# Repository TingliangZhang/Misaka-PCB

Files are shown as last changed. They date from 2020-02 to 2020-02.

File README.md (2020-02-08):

# Misaka-PCB

计划在设计完SCH电路图之后，改用KiCAD画，并全程录屏做延时视频。

## BOM智能配单

https://bom.szlcsc.com/bom.html

为了BOM配单方便，尽可能使用JLC-SMT库

[嘉立创](https://www.sz-jlc.com/)把 SMT支持的器件做成了要一个集成库

下载方法:   [嘉立创SMT](https://gitee.com/JLC_SMT) **/** [JLCSMT_LIB](https://gitee.com/JLC_SMT/JLCSMT_LIB)

导入Project Outputs for Miscellaneous Devices LC中的Miscellaneous Devices LC.IntLib

## USB 2.0 to USB Type-C

[**How to easily move from USB 2.0 to USB Type-C**](http://e2e.ti.com/blogs_/b/analogwire/archive/2015/09/02/how-to-easily-move-from-usb-2-0-to-usb-type-c)

[Oh Say Can You C? – Grappling with the USB type-C Connector](https://resources.orcad.com/orcad-blog/oh-say-can-you-c-grappling-with-the-usb-type-c-connector)

[Type-A接口改成Type-c接口的实验设计](http://www.elecfans.com/emb/jiekou/20190505929062.html)

## PCB Design Rules

SMD Pads Clearance -- 0.2 mil

TH Pads Clearance -- 0.15 mil

SMD Pads - Fill Clearance -- 0 mil   SMD Pads - Track -- 0 mil     XBEE模块的天线KEEPOUT FILL

## 元件选型说明

原Mega 2560中 LMV358IDGKR 立创商城需订货，改为LM358DR2G通用运放

原Mega 2560中 MH2029-300Y 磁珠 ，改为 BLM21PG300SN1D 0805 30 欧 @ 100MHz

MF-MSMF050 0.5A 15V 自恢复保险丝 立创商城需订货，改为 https://item.szlcsc.com/13192.html （相同封装）

俩RESET不要选元件

CG0603MLC-05E  ESD 抑制器/TVS 二极管，立创商城无货，改为[**0603ESDA-05N**](https://item.szlcsc.com/297742.html)

## PCB注意事项

和DTR 隔着100nF的Reset要连着和+5V隔着10kOhm的焊盘，以便SMT跳线能起作用。

X为水平左右翻转；Y为垂直上下翻转

## Cadence/OrCAD

Cadence Orcad Allegro Sigrity相关软件资源下载

https://www.mr-wu.cn/cadence-orcad-allegro-resource-downloads/

在线编辑器

**https://orcadcloud.ema-eda.com/**

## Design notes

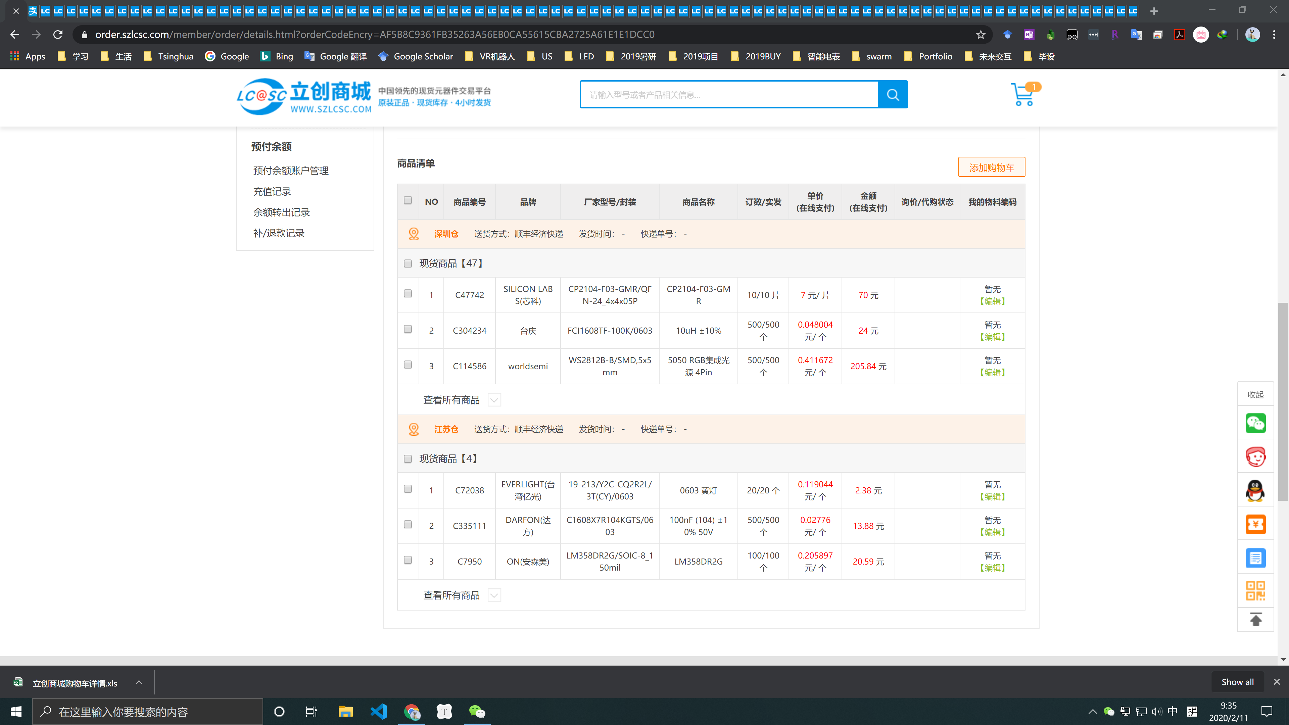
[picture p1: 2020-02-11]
ScreenShoot/批注 2020-02-11 093619.png

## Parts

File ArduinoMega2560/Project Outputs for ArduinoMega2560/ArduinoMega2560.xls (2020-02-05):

Item # | Designator | Description | Comment | Quantity | #Column Name Error:' Manufacturer 1 | #Column Name Error:' Manufacturer Part Number 1 | Footprint | LibRef | #Column Name Error:' Note
1 | C1, C2, C6, C7, C8, C9, C11, C12, C13, C14, C18 | 贴片电容 | 100nF | 11 |  |  | 0603_C | 0603 100nF (104) 10% 50V
2 | C3, C4 | Aluminum Electrolytic Capacitor, 47 uF, +/- 20%, 35 V, 2-Pin SMD (Size Code D), -55 to 105 degC, RoHS, Tape and Reel | EEEFP1V470AP | 2 |  |  | PNSC-FP-V-D_V | CMP-2000-06216-1
3 | C5, C10 | 贴片电容 | 1uF (105) 10% 50V | 2 |  |  | 0603_C | 0603 1uF (105) 10% 50V
4 | C15, C16, C17 | 贴片电容 | 22pF (220) 5% 50V | 3 |  |  | 0603_C | 0603 22pF (220) 5% 50V
5 | D1 | 二极管 | M7 | 1 |  |  | SMA(DO-214AC)_S1 | SMA(DO-214AC) M7
6 | D2, D3 | 75 V Small Signal Switching Diode, 150 mA, 2.5 uA, 1026 Molded Package, RoHS, Tape and Reel | CD1206-S01575 | 2 |  |  | BOUR-CD1206-S01575-2_L | CMP-0583-00001-2
7 | F1 | PTC Resettable Fuse, 15 V, 500 mA, -40 to 85 degC, 2-Pin SMD, RoHS, Tape and Reel | SMD1812P050TF | 1 |  |  | BOUR-MF-MSMF050-2_V | CMP-2100-03653-1
8 | FB1 | Chip Ferrite Bead for Power Lines, 30 Ohm, 4000 mA, -55 to 125 degC, 2 x 1.25 x 1.05 mm SMD, Tape and Reel | BLM21PG300SN1D | 1 |  |  | MURA-BLM21-B40-CHIP-2_V2 | CMP-0686-00620-2
9 | GROUND-EN1, RESET-EN1 | Chip Resistor, 0 Ohm, +/- 5%, -55 to 155 degC, 1206 (3216 Metric), RoHS, Tape and Reel | RC1206JR-070RL | 2 |  |  | RESC3116X65X40ML10T20 | CMP-2100-03681-1
10 | IC1 | Low-dropout linear regulator 5V -LM1117IMPX-5.0 Fixed Low Drop Positive Voltage Regulator, 5V, 4-Pin SOT-223, Tape and Reel | LD1117S50CTR | 1 |  |  | SOT-223_N | CMP-0244-00311-1
11 | IC2 | 8-bit AVR Microcontroller, 4.5-5.5V, 16MHz, 256KB Flash, 4KB EEPROM, 8KB SRAM, 86 GPIO pins, 100-pin TQFP, Industrial Grade (-40°C to 85°C), Pb-Free | ATmega2560-16AU | 1 |  |  | 100A_M | CMP-0095-00210-2
12 | IC3 | Single Output Low Noise LDO, 150 mA, Fixed 3.3 V Output, 1.5% Tolerance, 2.2 to 16 V Input, Low IQ, 5-Pin SOT-23 (DBV), -40 to 125 degC, Green (RoHS & no Sb/Br), Tape and Reel | LP2985-33DBVR | 1 |  |  | DBV0005A_M | CMP-0758-00080-2
13 | IC4 | 8-bit AVR Microcontroller, 2.7-5.5V, 16KB Flash, 512 Bytes EEPROM, 512 Bytes SRAM, 32-pin VQFN, Industrial Grade (-40°C to 85°C) | ATmega16U2-MU | 1 |  |  | 32PG_N | CMP-0095-00115-3
14 | J1 | Micro-USB B Receptacle with Flange, -30 to 85 degC, 5-Pin SMD, RoHS, Tape and Reel | 47346-0001 | 1 |  |  | MOLX-47346-0001-5_V | CMP-2000-05246-1
15 | J2 | USB 3.1 Type C Receptacle WR-COM, Horizontal, SMT / THT | USB 3.1 C TYPE DIP+SMT CONN | 1 |  |  | 632723100011 | CMP-1502-03213-1
16 | L1 | 贴片电感 | 10uH ±10% | 1 |  |  | 0603_L | 0603 10uH 10%
17 | L2, RX1, TX1 | 发光二极管 | 黄灯 0603 | 3 |  |  | 0603_LED_S1 | 0603 黄灯
18 | ON1 | 发光二极管 | 翠绿 0805 | 1 |  |  | 0805_LED_S1 | 0805 翠绿
19 | P1, P2 | Header, 3-Pin, Dual row | Header 3X2 | 2 |  |  | HDR2X3 | Header 3X2
20 | Q1 | MOS(场效应管) | AO3401A P道沟 X13A15 SOT-23 | 1 |  |  | SOT-23-3L | AO3401A P道沟 X13A15 SOT-23
21 | R1, R2 | 贴片电阻 | 22Ω (22R0) ±1% | 2 |  |  | 0603_R | 0603 22Ω (22R0) 1%
22 | R3, R6, R13 | 贴片电阻 | 1KΩ (1001) ±1% | 3 |  |  | 0603_R | 0603 1KΩ (1001) 1%
23 | R4, R5, R7, R8, R10, R11 | 贴片电阻 | 10KΩ (1002) ±1% | 6 |  |  | 0603_R | 0603 10KΩ (1002) 1%
24 | R9, R12 | 贴片电阻 | 1MΩ (1004) ±1% | 2 |  |  | 0603_R | 0603 1MΩ (1004) 1%
25 | RESET1 | WS-TASV SMD Tact Switch 6X6 mm | 轻触开关 6*6 | 1 |  |  | 430152043836 | CMP-1452-00002-1
26 | Rp1 | 贴片排阻 | 1KΩ (102) ±5% | 1 |  |  | 0603_Rx4 | 0603*4 1KΩ (102) 5%
27 | U1 | 通用运放 | LM358DR2G | 1 |  |  | SOIC-8_150mil | LM358DR2G_[C7950]
28 | U? | Toshiba Bi-CD Integrated Circuit Silicon Monolithicr, 2.7 to 5.5 V, 1 A, -20 to 85 degC, 24-Pin SSOP, RoHS, Tape and Reel | TB6612FNG(O,C,8,EL | 1 |  |  | TOSH-SSOP24-P-300-0.65A_M | CMP-2100-03693-1
29 | U? | Intelligent Control LED Integrated Light Source, 3.5 to 5.3 V, -25 to 80 degC, 4-Pin SMD, RoHS, Tape and Reel 1655 | WS2812B | 1 |  |  | ADA-RGB-1655_V | CMP-2000-05026-1
30 | X1 | Header, 2-Pin | Header 2 | 1 |  |  | HDR1X2 | Header 2
31 | Y1 | 贴片晶振 | 16MHZ 9PF 10PPM | 1 |  |  | SMD-3225_4P | SMD-3225_4P 16MHZ 9PF 10PPM
32 | Y2 | Ceramic Resonator, 16 MHz with Built-in Capacitance, Thickness Expander Mode, Initial Frequency Tolerance +/- 0.5%, Load Capacity 15 pF, -20 to 80 degC, 3.2 x 1.3 x 1 mm SMD, RoHS, Reel | CSTCE16M0V53-R0 | 1 |  |  | MURA-CSTCE_V-3_V | CMP-0588-00001-2
33 | Z1, Z2 | ESD Protector, 5 V Supply, -40 to 85 degC, 1.6 x 0.8 x 0.55 mm SMD, RoHS, Tape and Reel | CG0603MLC-05E | 2 |  |  | BOUR-CG0603-2_V | CMP-0584-00001-2

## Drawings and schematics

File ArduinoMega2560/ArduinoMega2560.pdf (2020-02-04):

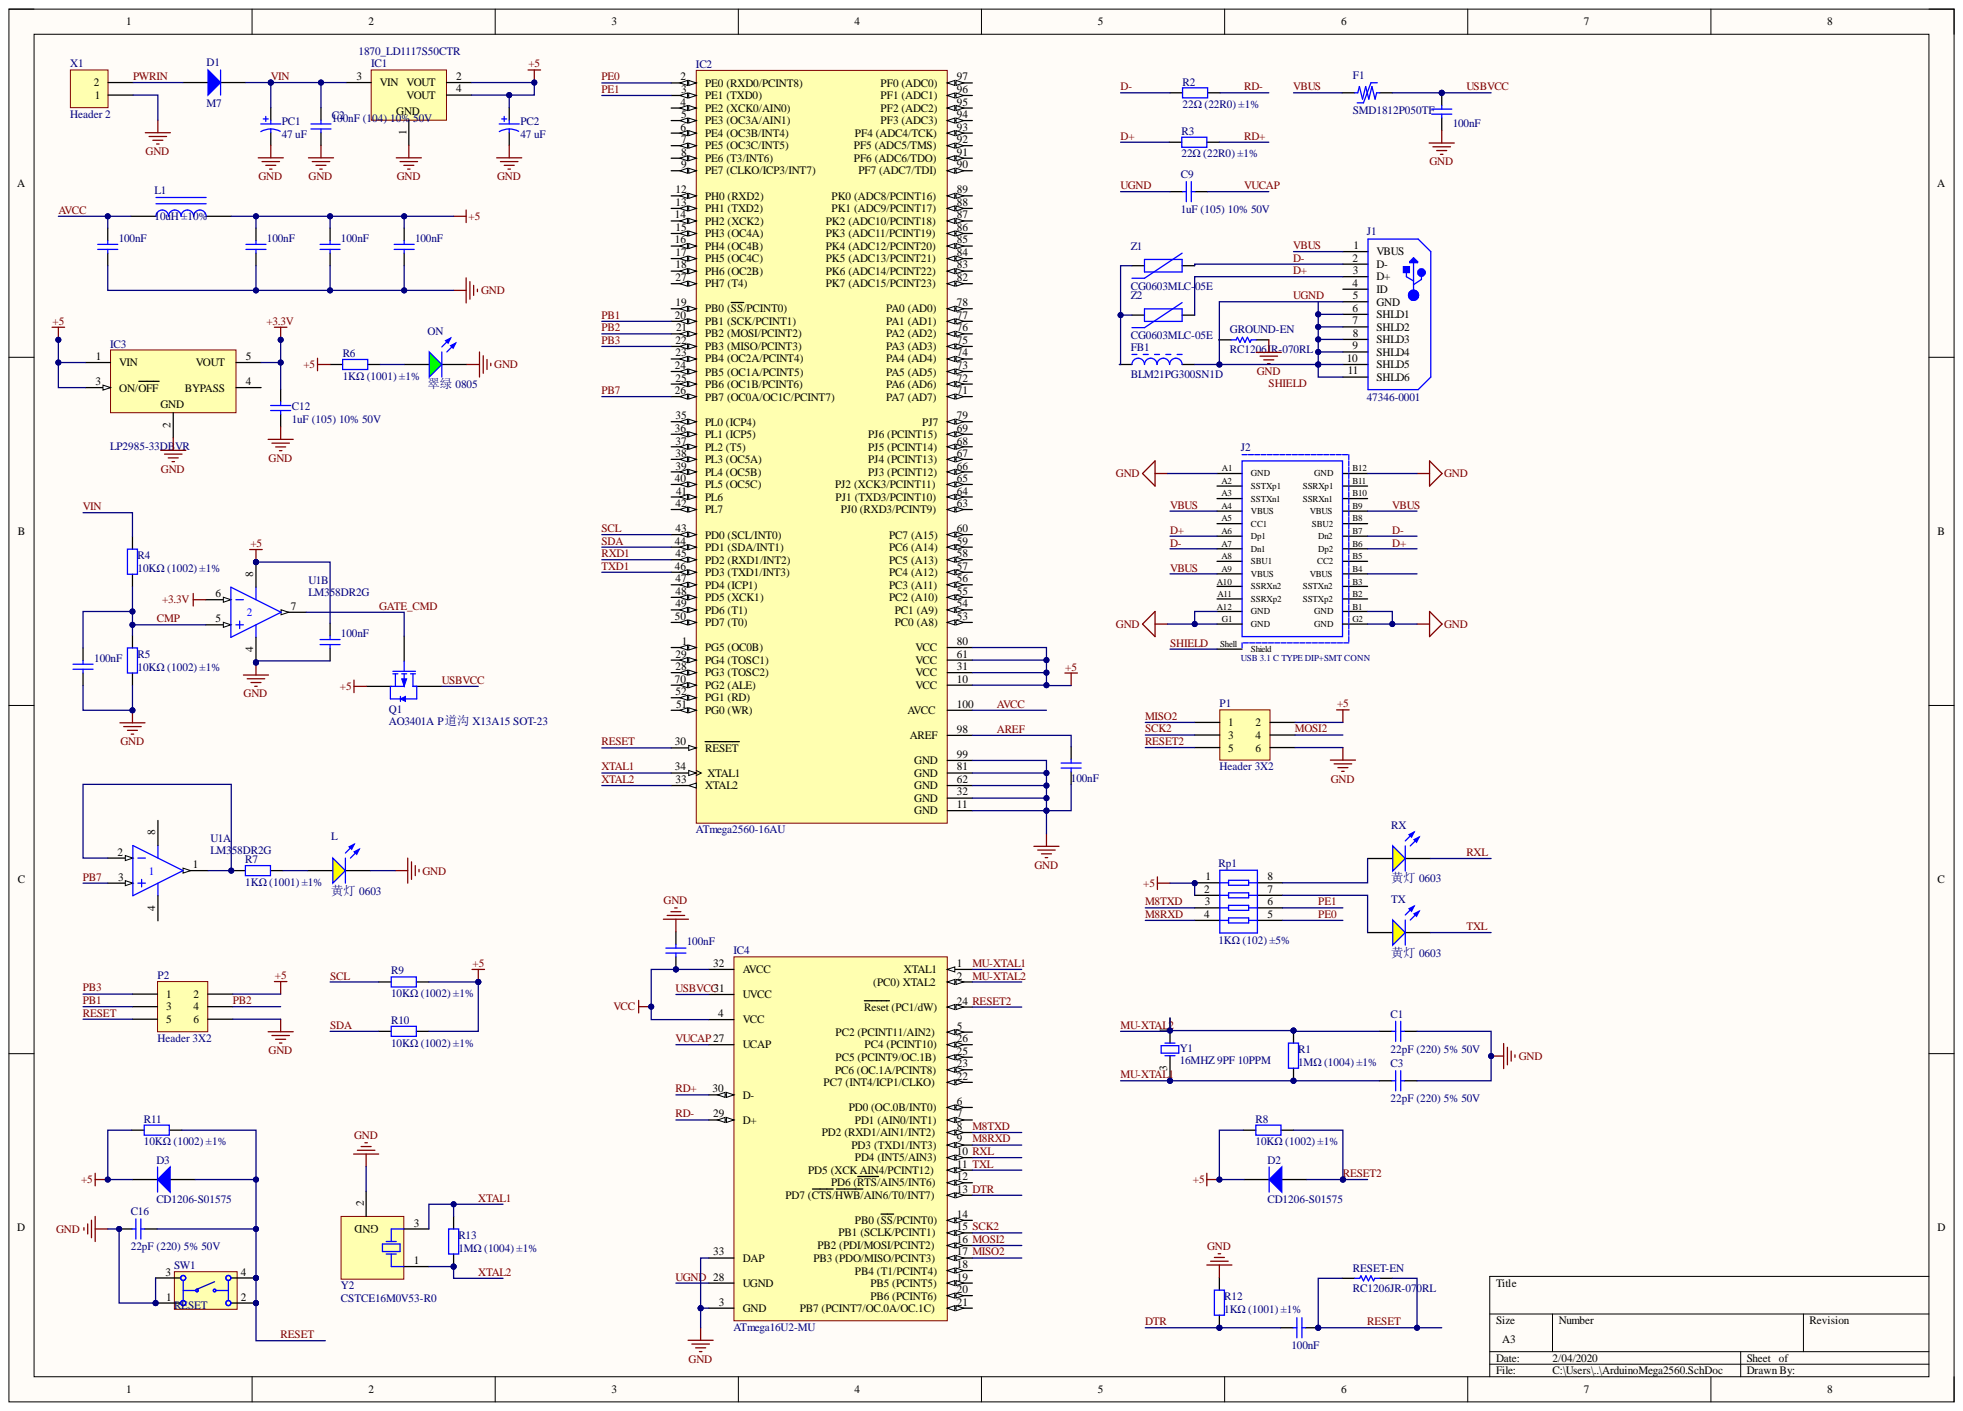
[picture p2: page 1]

SHLD1 6

GROUND-EN RC1206JR-070RL | SHLD2 7

SHLD3 8
SHLD4 9

Shield Shell
USB 3.1 C TYPE DIP+SMT CONN

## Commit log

2020-02-02 Light Switch
    [ArduinoMega2560.PcbDoc, ArduinoMega2560.SchDoc]
2020-02-02 A3-A4 Size
    [ArduinoMega2560-A4.SchDoc, ArduinoMega2560.PcbDoc, ArduinoMega2560.PrjPcb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]
2020-02-02 BOM智能配单
2020-02-03 JLC-SMT Lib
    [ArduinoMega2560.SchDoc, Cap.SchLib, CrystalOscillator.SchLib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]
2020-02-03 USB Type-C
    [ArduinoMega2560.PcbDoc, ArduinoMega2560.SchDoc]
2020-02-04 Finish Mega2560-Sch
    [ArduinoMega2560.PcbDoc, ArduinoMega2560.SchDoc]
2020-02-05 PC Too High
    [ArduinoMega2560.PcbDoc, ArduinoMega2560.SchDoc, ArduinoMega2560.xls]
2020-02-05 换回来了，我怕钽电容炸
    [ArduinoMega2560.PcbDoc, ArduinoMega2560.SchDoc]
2020-02-05 Using CP2102N
    [ArduinoMega2560.PcbDoc, ArduinoMega2560.SchDoc]
2020-02-06 Finish CP2104
    [ArduinoMega2560.SchDoc]
2020-02-06 UART 3.3V
    [ArduinoMega2560.SchDoc]
2020-02-07 Battery Connecter
    [ArduinoMega2560.SchDoc]
2020-02-08 Pin assign TB6612
    [ArduinoMega2560.SchDoc]
2020-02-08 ATmega2560-16AU AND ESP-WROOM-32 Communication Port
    [ArduinoMega2560.SchDoc]
2020-02-08 ADD powerSTEP01
    [ArduinoMega2560.PcbDoc, ArduinoMega2560.SchDoc]
2020-02-09 ST powerSTEP01 SINGLE UNCONNECTED
    Mega2560双SPI不知道该怎么搞
    [ArduinoMega2560.SchDoc]
2020-02-09 Theory Part Almost Finished Edition
    [ArduinoMega2560.PcbDoc, ArduinoMega2560.SchDoc]
2020-02-09 ADD CAMERA
    [Misaka-v1.0.PcbDoc, Misaka-v1.0.SchDoc]
2020-02-09 BOARD 100X100
    [Misaka-v1.0.PrjPcb, Misaka-v1.0.SchDoc, Misaka-v1.0.xlsx]
2020-02-10 CONNECT GROUND-EN1
    [Misaka-v1.0.SchDoc]
2020-02-10 Squared 方方正正的
2020-02-10 Rectangular 长方形板
2020-02-10 BOM Error
    [Fabrication Testpoint Report for Misaka-v1.0.csv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]
2020-02-10 Misaka v2.0 Manufactured
    [Misaka-v1.0.PrjPcb, Misaka-v1.0.SchDoc, Misaka-v1.0.xlsx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]
2020-02-10 Output PDF
    [Misaka-v1.0.PrjPcb]
2020-02-10 A1 to 630x400
    [Misaka-v1.0.SchDoc]
